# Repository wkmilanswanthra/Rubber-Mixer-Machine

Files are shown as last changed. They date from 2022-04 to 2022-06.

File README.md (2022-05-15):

# Rubber Mixer v1.0


## :eyes: Special considerations when uploading code
* Always create a **_new branch_** to upload new and edited code
* Fetch origin before making any changes to your code
* Add a well written description to each commit
* Mention every single change done
* Create a pull request and merge the branch in the main after resolving any conflicts
* If you face any problems when merging a branch watch [this video](https://youtu.be/9j0AOrO0dnw?t=1086) or contact me :full_moon_with_face: 
* Use the seperate folder named "Proteus files" to upload any proteus project files 
* Use the seperate folder named "test2" to upload new or changed header files 

## Components that need to be completed
* - [ ] Code for the Ultrasonic sensor (Detect the liquid levels once before the LCD Display starts)
* - [ ] Code for the calculation of pH values and required volumes

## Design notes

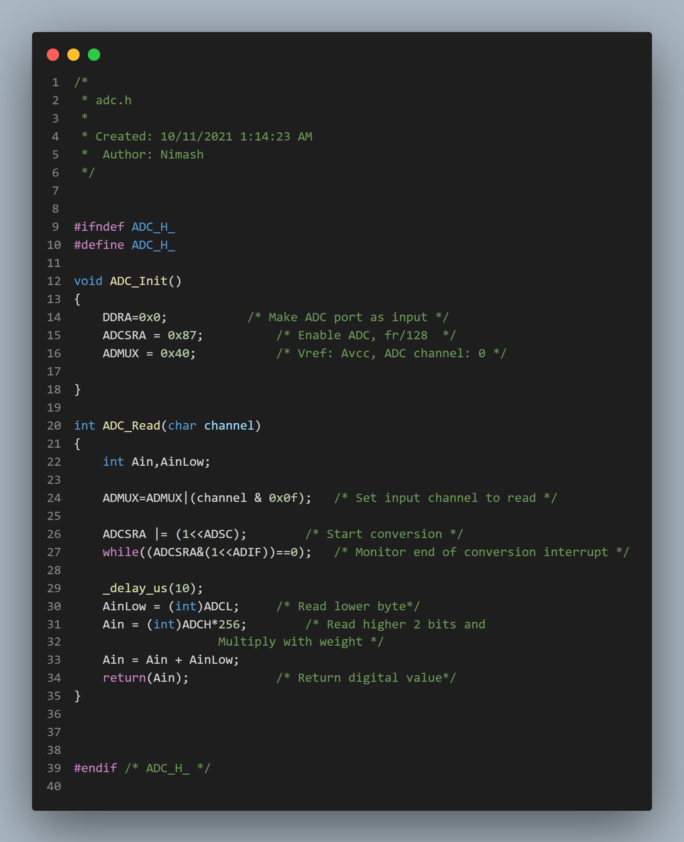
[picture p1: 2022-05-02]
NImz/code snaps/adc-h.png

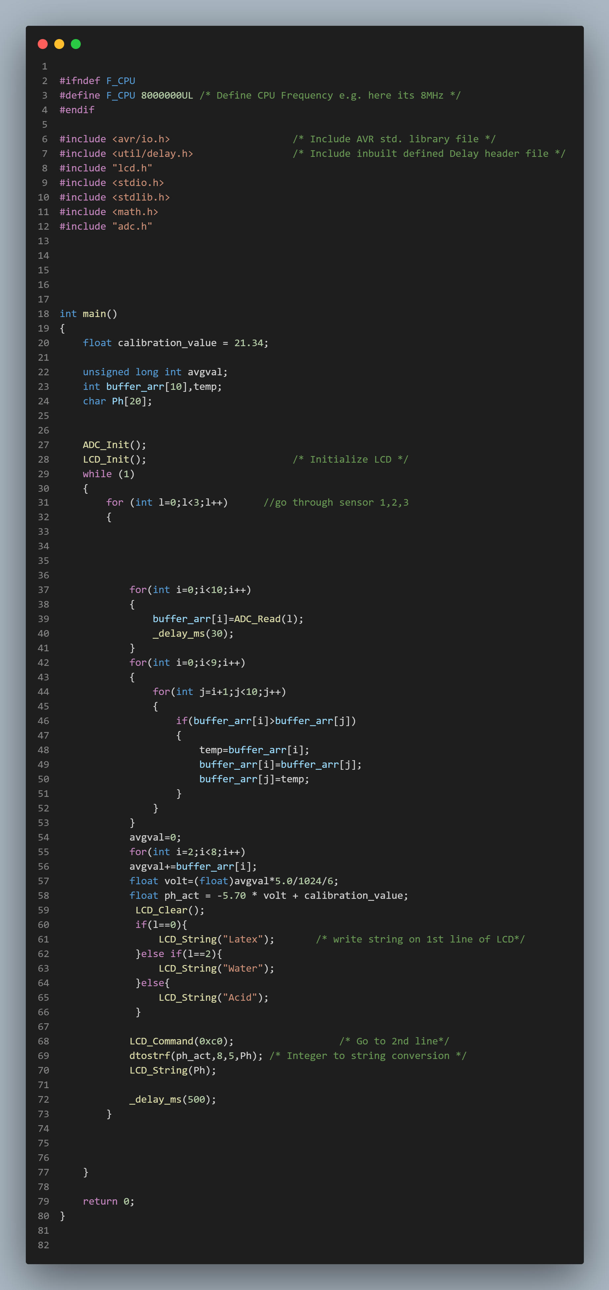
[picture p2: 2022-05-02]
NImz/code snaps/main-c.png

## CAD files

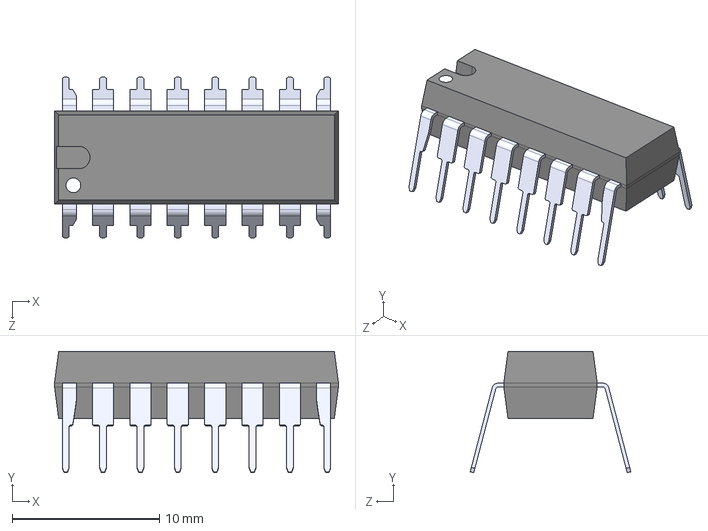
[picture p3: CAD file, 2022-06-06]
PCB and schematic/footprints/4052/CD4052BE.STEP
19.3 x 8.25 x 10.9 mm

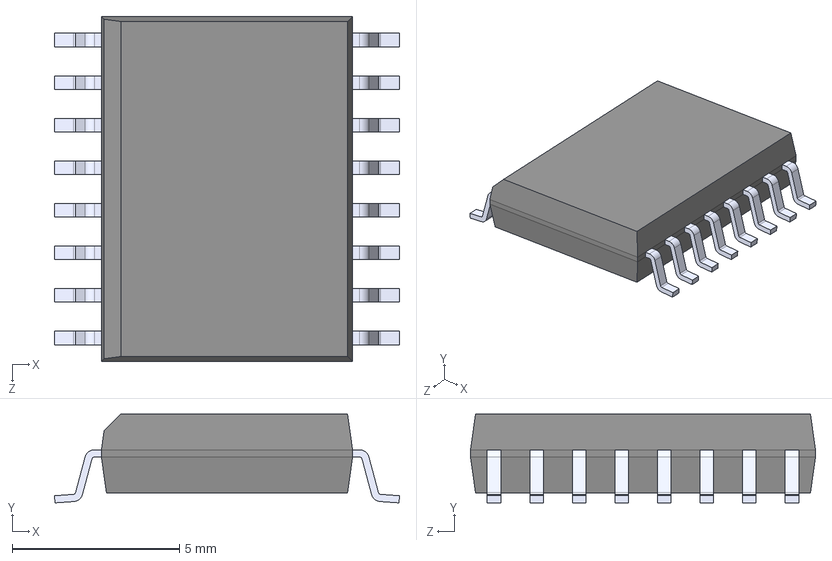
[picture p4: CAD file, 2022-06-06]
PCB and schematic/footprints/pcf8574a/i2c part 3/PCF8574ADW.step
10.3 x 2.65 x 10.3 mm

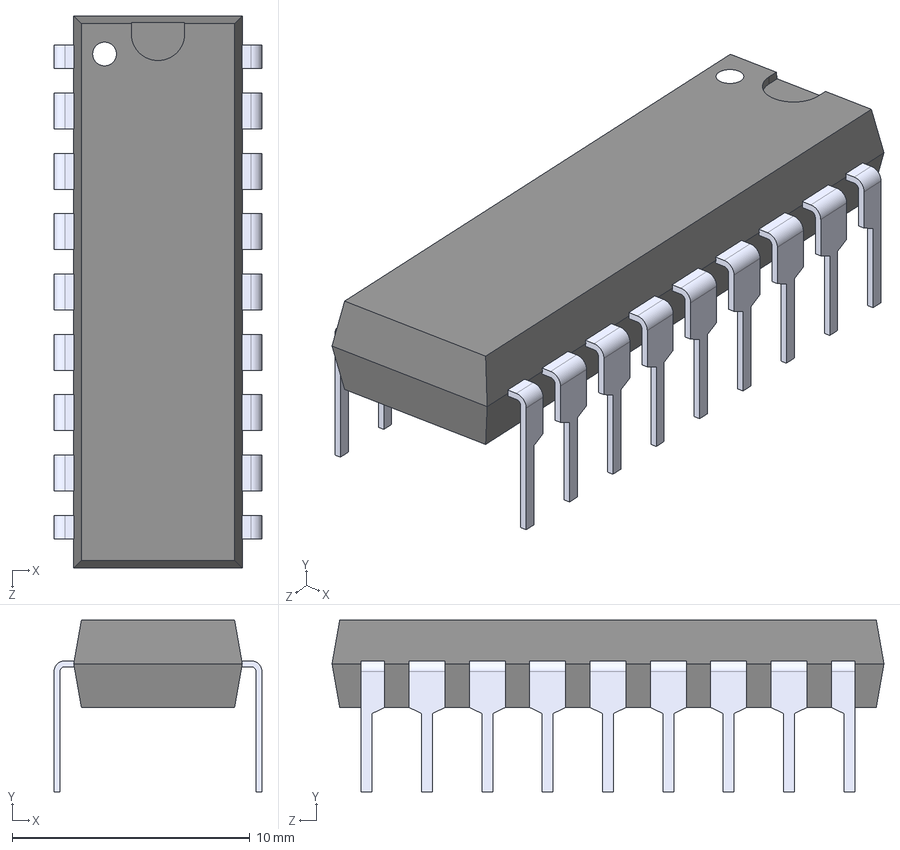
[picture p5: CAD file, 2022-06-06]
PCB and schematic/footprints/uln2803a/ULN2803A.step
8.75 x 7.23 x 23.2 mm

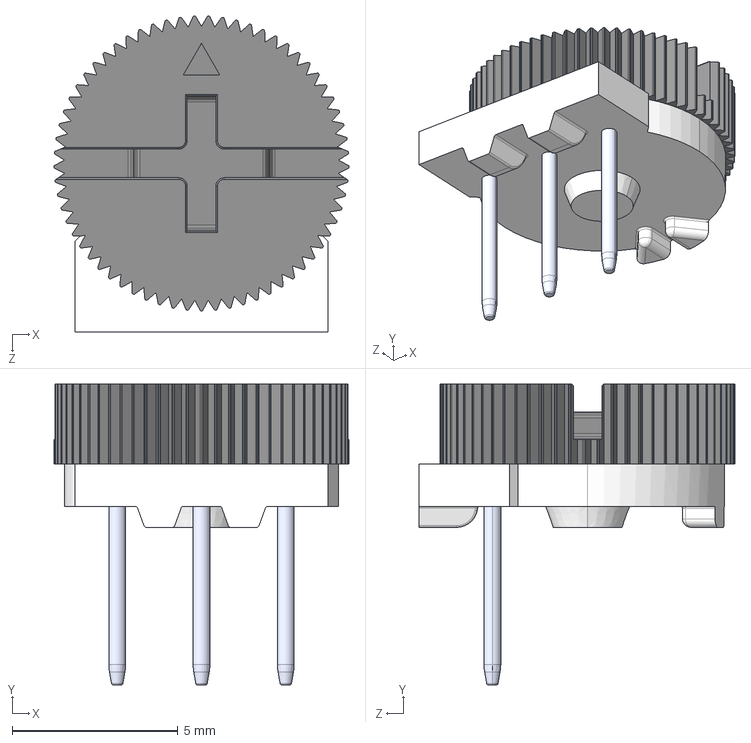
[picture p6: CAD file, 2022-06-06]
PCB and schematic/footprints/variable resistor/3352T-1-254LF.step
8.89 x 9.07 x 9.52 mm

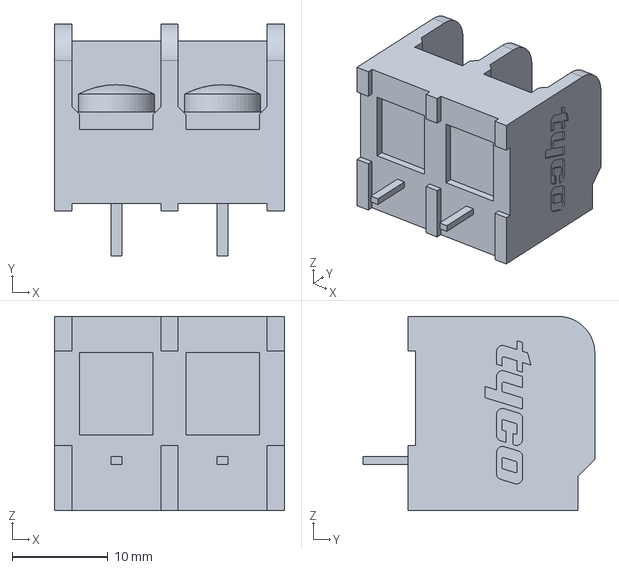
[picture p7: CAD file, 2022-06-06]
PCB and schematic/Milan - pcb/milan new/Symbols/5-1437657-7.step
24.1 x 24.3 x 20.3 mm

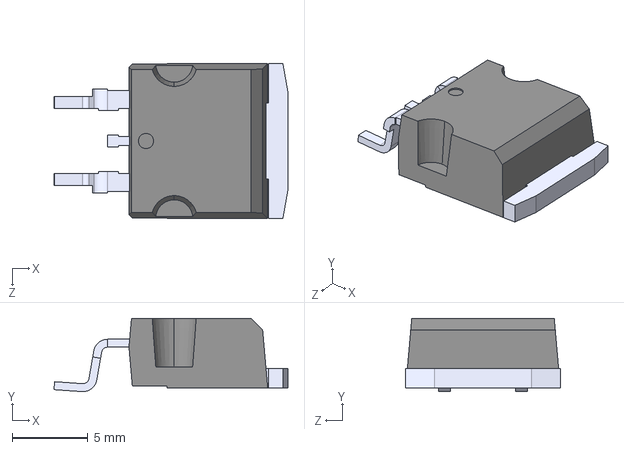
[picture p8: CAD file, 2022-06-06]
PCB and schematic/power supply/footprints/L7812.step
15.4 x 4.83 x 10.2 mm

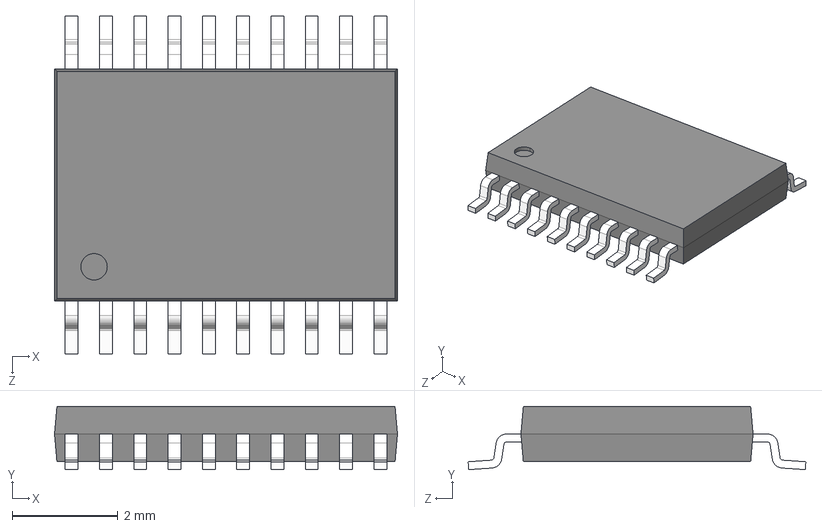
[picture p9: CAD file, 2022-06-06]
PCB and schematic/footprints/pcf8574a/PCF8574A.step
6.50 x 1.20 x 6.40 mm

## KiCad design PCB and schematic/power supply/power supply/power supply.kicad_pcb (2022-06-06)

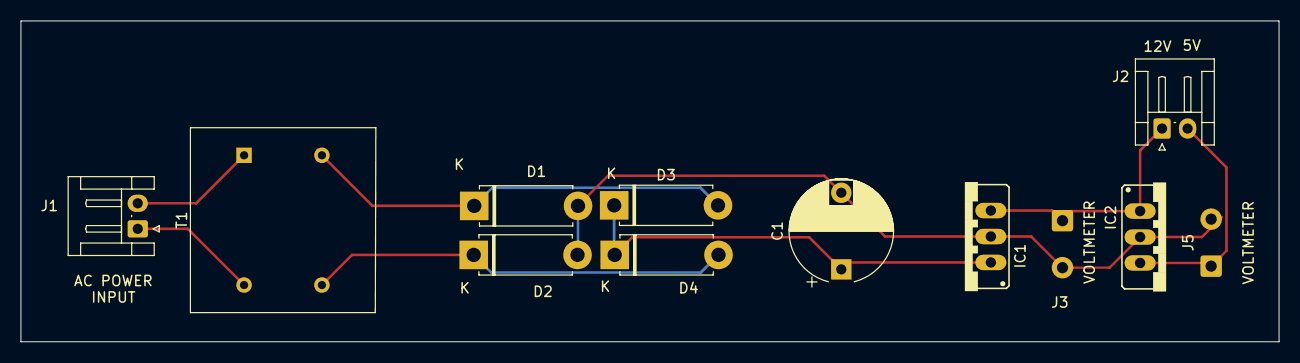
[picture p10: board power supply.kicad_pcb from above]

Board: 2 copper layers, 123.1 x 31.4 mm, 12 parts (0 on the bottom side), 7 nets.

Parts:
C1: C_Polarized; CP_Radial_D10.0mm_P7.50mm
D1, D2, D3, D4: D; D_5W_P10.16mm_Horizontal
IC1, IC2: L7812; 78XXS
J1, J2: Conn_01x02_Female; JST_EH_S2B-EH_1x02_P2.50mm_Horizontal
J3, J5: Conn_01x02_Female; SolderWire-0.5sqmm_1x02_P4.6mm_D0.9mm_OD2.1mm
T1: Transformer_1P_1S; Transformer_NF_ETAL_P3324

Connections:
-VDC: C1.2, D1.2 (A), D2.2 (A), IC1.GND, IC2.GND, J3.2, J5.2
unnamed: D1.1 (K), D3.2 (A), T1.3 (SB)
unnamed: D2.1 (K), D4.2 (A), T1.4 (SA)
unnamed: IC1.OUT, IC2.IN, J2.1, J3.1
unnamed: IC2.OUT, J2.2, J5.1
VAC: J1.1, J1.2, T1.1 (AA), T1.6 (AB)
VS: C1.1, D3.1 (K), D4.1 (K), IC1.IN

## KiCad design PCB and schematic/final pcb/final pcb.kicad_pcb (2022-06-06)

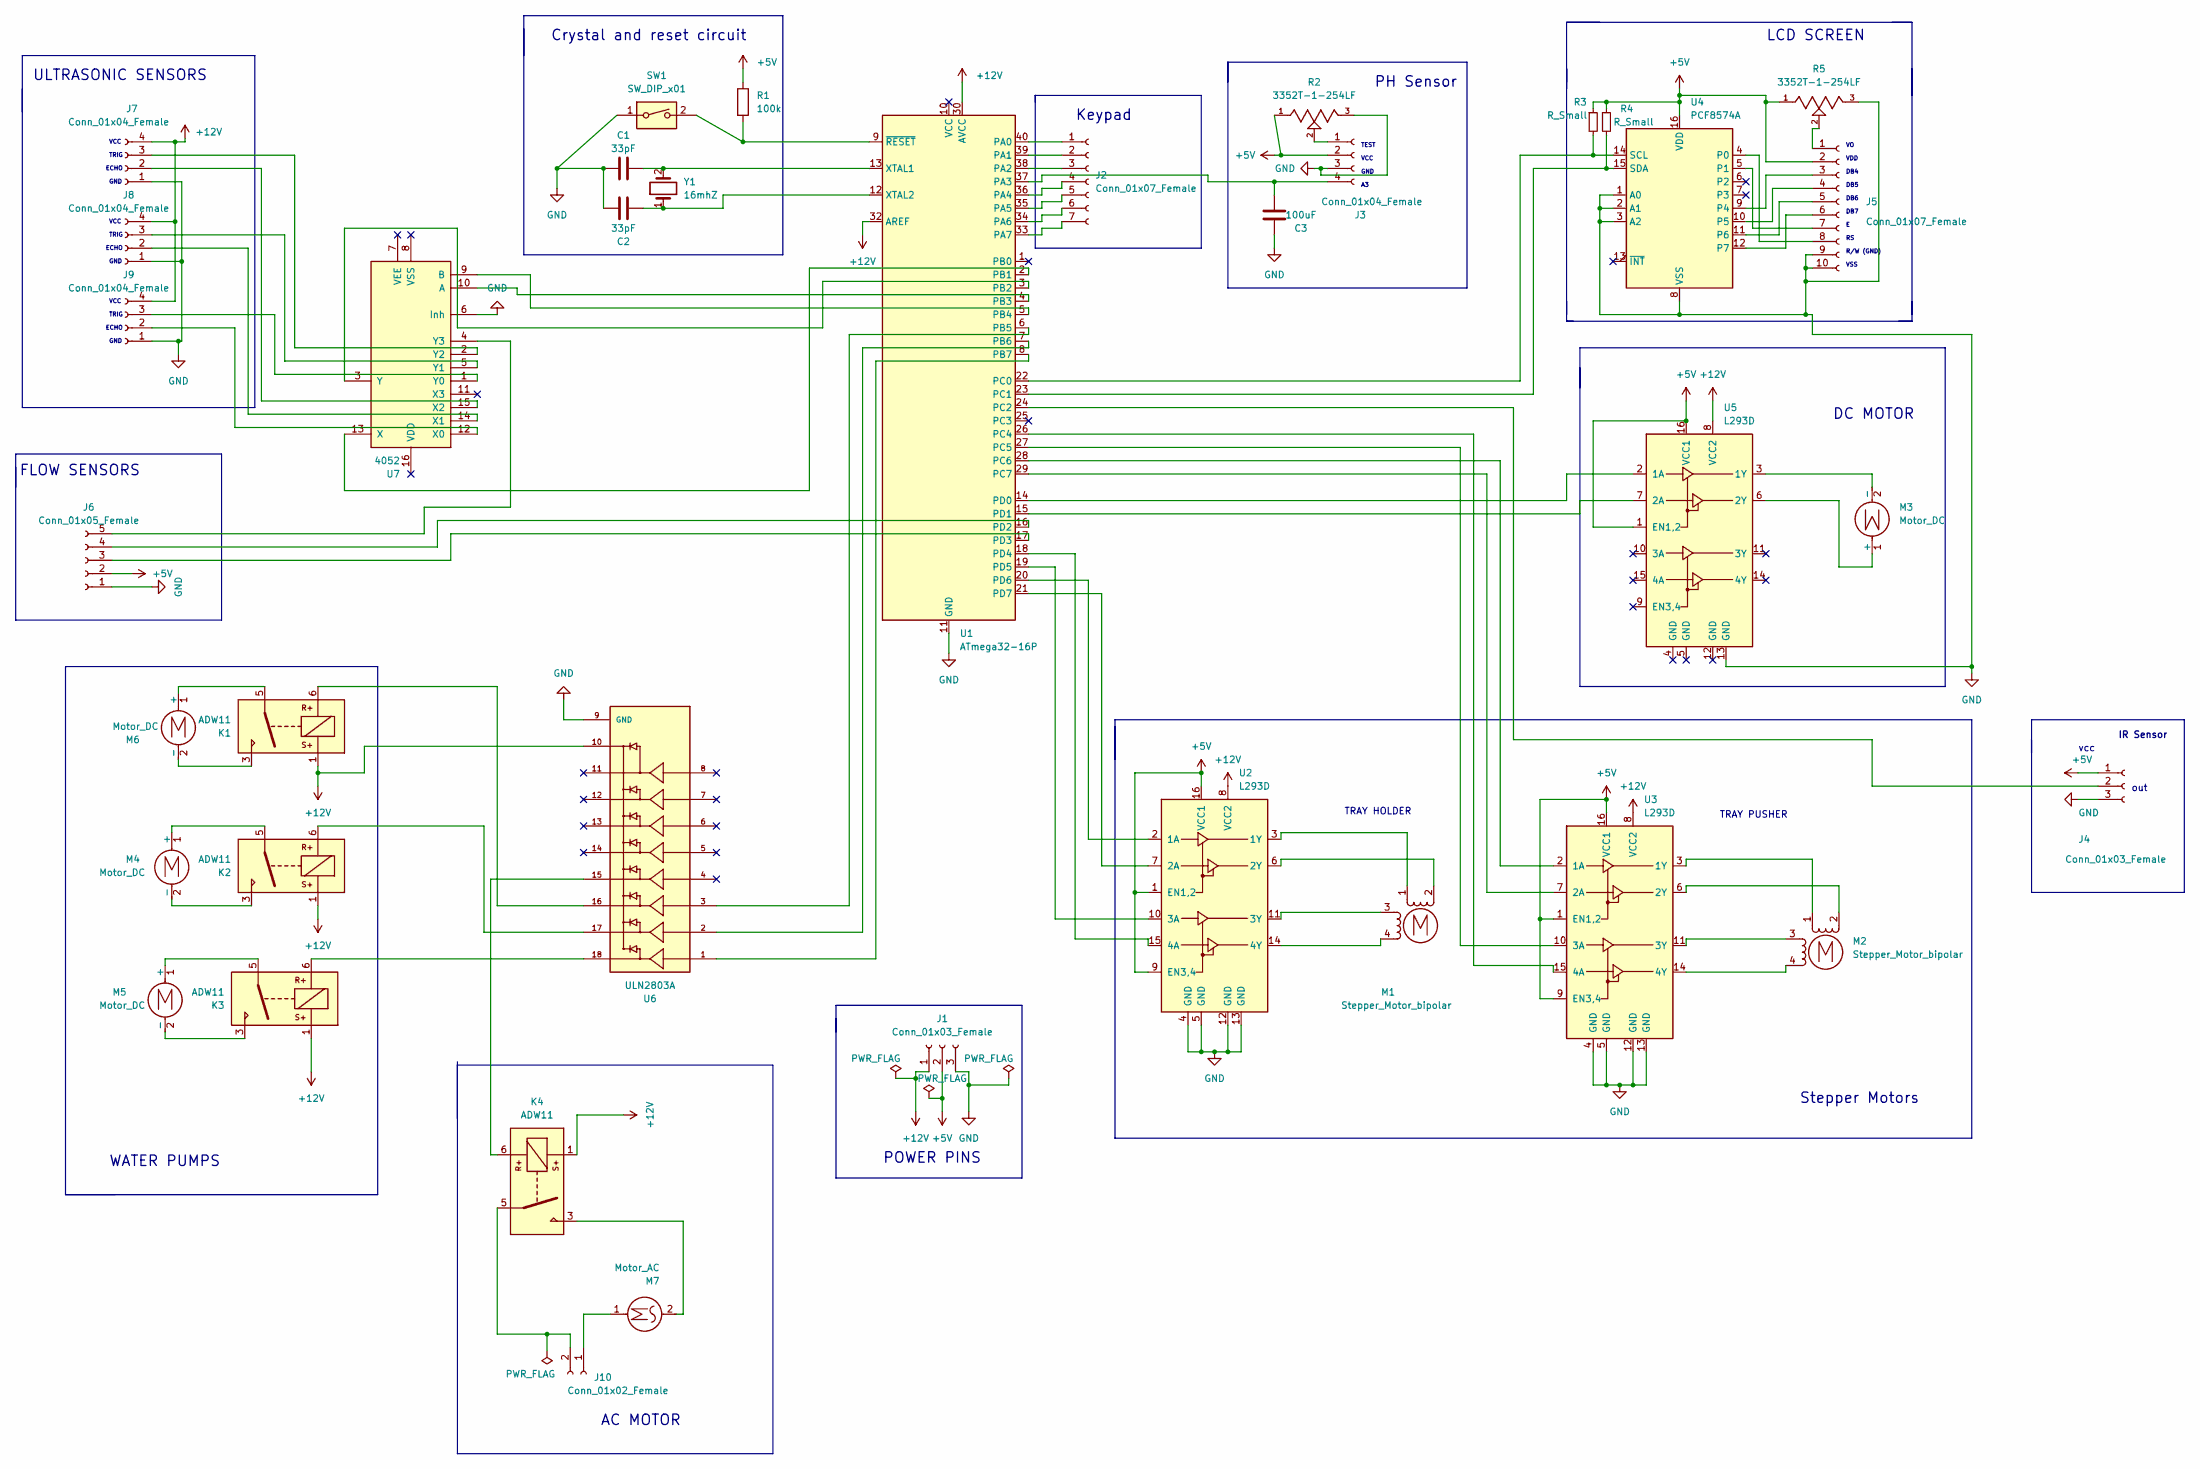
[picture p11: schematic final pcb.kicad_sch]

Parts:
C1: 33pF; C_Disc_D7.0mm_W2.5mm_P5.00mm
C2: 33pF; C_Disc_D7.5mm_W2.5mm_P5.00mm
C3: 100uF; C_Disc_D7.5mm_W2.5mm_P5.00mm
J1: Conn_01x03_Female; JST_EH_S3B-EH_1x03_P2.50mm_Horizontal
J2: Conn_01x07_Female; JST_EH_S7B-EH_1x07_P2.50mm_Horizontal
J3: Conn_01x04_Female; SolderWire-0.1sqmm_1x04_P3.6mm_D0.4mm_OD1mm
J4: Conn_01x03_Female; PinHeader_1x03_P2.54mm_Horizontal
J5: Conn_01x07_Female; JST_EH_S10B-EH_1x10_P2.50mm_Horizontal
J6: Conn_01x05_Female; JST_EH_S5B-EH_1x05_P2.50mm_Horizontal
J7, J8, J9: Conn_01x04_Female; JST_EH_S4B-EH_1x04_P2.50mm_Horizontal
J10: Conn_01x02_Female; JST_EH_B2B-EH-A_1x02_P2.50mm_Vertical
K1, K2, K3, K4: ADW11; Relay_1P1T_NO_10x24x18.8mm_Panasonic_ADW11xxxxW_THT
M1, M2: Stepper_Motor_bipolar; PinHeader_1x04_P2.54mm_Horizontal
M3, M4, M5, M6: Motor_DC; PinHeader_1x02_P2.54mm_Horizontal
M7: Motor_AC; PinHeader_1x02_P2.54mm_Horizontal
R1: 100k; R_Axial_DIN0204_L3.6mm_D1.6mm_P7.62mm_Horizontal
R2, R5: 3352T-1-254LF; TRIM_3352T-1-254LF; PARTREV 08/19
R3, R4: R_Small; R_0402_1005Metric
SW1: SW_DIP_x01; SW_DIP_SPSTx01_Slide_6.7x4.1mm_W7.62mm_P2.54mm_LowProfile
U1: ATmega32-16P; DIP-40_W15.24mm
U2, U3, U5: L293D; DIP-16_W7.62mm
U4: PCF8574A; SOIC127P1030X265-16N
U6: ULN2803A; DIP850W46P254L2324H393Q18; PARTREV 4
U7: 4052; DIP794W45P254L1969H508Q16
Y1: 16mhZ; Crystal_C38-LF_D3.0mm_L8.0mm_Vertical

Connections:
+5V: J1.2, J3.2, J4.1, J5.2, J6.2, R1.1, R2.1, R3.1, R4.1, R5.1, U2.1 (EN1,2), U2.9 (EN3,4), U2.16 (VCC1), U3.1 (EN1,2), U3.9 (EN3,4), U3.16 (VCC1), U4.16 (VDD), U5.1 (EN1,2), U5.16 (VCC1)
+12V: J1.1, J7.4, J8.4, J9.4, K1.1, K2.1, K3.1, K4.1, U1.30 (AVCC), U1.32 (AREF), U2.8 (VCC2), U3.8 (VCC2), U5.8 (VCC2), U6.10
GND: C1.2, C2.2, C3.2, J1.3, J3.3, J4.3, J5.9, J5.10, J6.1, J7.1, J8.1, J9.1, R2.3, R5.3, SW1.1, U1.11 (GND), U1.31 (GND), U2.4 (GND), U2.5 (GND), U2.12 (GND), U2.13 (GND), U3.4 (GND), U3.5 (GND), U3.12 (GND), U3.13 (GND), U4.1 (A0), U4.2 (A1), U4.3 (A2), U4.8 (VSS), U5.13 (GND), U6.9 (GND), U7.6 (Inh)
unnamed: C1.1, U1.13 (XTAL1), Y1.2
unnamed: C2.1, U1.12 (XTAL2), Y1.1
unnamed: C3.1, J3.4, U1.37 (PA3)
unnamed: J2.1, U1.40 (PA0)
unnamed: J2.2, U1.39 (PA1)
unnamed: J2.3, U1.38 (PA2)
unnamed: J2.4, U1.36 (PA4)
unnamed: J2.5, U1.35 (PA5)
unnamed: J2.6, U1.34 (PA6)
unnamed: J2.7, U1.33 (PA7)
unnamed: J3.1, R2.2
unnamed: J4.2, U1.24 (PC2)
unnamed: J5.1, R5.2
unnamed: J5.3, U4.9 (P4)
unnamed: J5.4, U4.10 (P5)
unnamed: J5.5, U4.11 (P6)
unnamed: J5.6, U4.12 (P7)
unnamed: J5.7, U4.5 (P1)
unnamed: J5.8, U4.4 (P0)
unnamed: J6.3, U1.17 (PD3)
unnamed: J6.4, U1.16 (PD2)
unnamed: J6.5, U7.4 (Y3)
unnamed: J7.2, U7.15 (X2)
unnamed: J7.3, U7.2 (Y2)
unnamed: J8.2, U7.14 (X1)
unnamed: J8.3, U7.5 (Y1)
unnamed: J9.2, U7.12 (X0)
unnamed: J9.3, U7.1 (Y0)
unnamed: J10.1, M7.1
unnamed: J10.2, K4.5
unnamed: K1.3, M6.2 (-)
unnamed: K1.5, M6.1 (+)
unnamed: K1.6, U6.16
unnamed: K2.3, M4.2 (-)
unnamed: K2.5, M4.1 (+)
unnamed: K2.6, U6.17
unnamed: K3.3, M5.2 (-)
unnamed: K3.5, M5.1 (+)
unnamed: K3.6, U6.18
unnamed: K4.3, M7.2
unnamed: K4.6, U6.15
unnamed: M1.1, U2.3 (1Y)
unnamed: M1.2 (-), U2.6 (2Y)
unnamed: M1.3, U2.11 (3Y)
unnamed: M1.4, U2.14 (4Y)
unnamed: M2.1, U3.3 (1Y)
unnamed: M2.2 (-), U3.6 (2Y)
unnamed: M2.3, U3.11 (3Y)
unnamed: M2.4, U3.14 (4Y)
unnamed: M3.1 (+), U5.6 (2Y)
unnamed: M3.2 (-), U5.3 (1Y)
unnamed: R1.2, SW1.2, U1.9 (~RESET)
unnamed: R3.2, U1.22 (PC0), U4.14 (SCL)
unnamed: R4.2, U1.23 (PC1), U4.15 (SDA)
unnamed: U1.2 (PB1), U7.13 (X)
unnamed: U1.3 (PB2), U7.3 (Y)
unnamed: U1.4 (PB3), U7.10 (A)
unnamed: U1.5 (PB4), U7.9 (B)
unnamed: U1.6 (PB5), U6.3
unnamed: U1.7 (PB6), U6.2
unnamed: U1.8 (PB7), U6.1
unnamed: U1.14 (PD0), U5.2 (1A)
unnamed: U1.15 (PD1), U5.7 (2A)
unnamed: U1.18 (PD4), U2.15 (4A)
unnamed: U1.19 (PD5), U2.10 (3A)
unnamed: U1.20 (PD6), U2.2 (1A)
unnamed: U1.21 (PD7), U2.7 (2A)
unnamed: U1.26 (PC4), U3.15 (4A)
unnamed: U1.27 (PC5), U3.10 (3A)
unnamed: U1.28 (PC6), U3.2 (1A)
unnamed: U1.29 (PC7), U3.7 (2A)

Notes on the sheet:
TRIG
GND
TRAY PUSHER
DC MOTOR
VCC
R/W (GND)
VSS
out
VDD
AC MOTOR
FLOW SENSORS
ECHO
DB5
DB7
PH Sensor
LCD SCREEN
DB4
Crystal and reset circuit
IR Sensor
vcc
ULTRASONIC SENSORS
TRAY HOLDER
WATER PUMPS
TEST
Keypad
POWER PINS
Stepper Motors
DB6

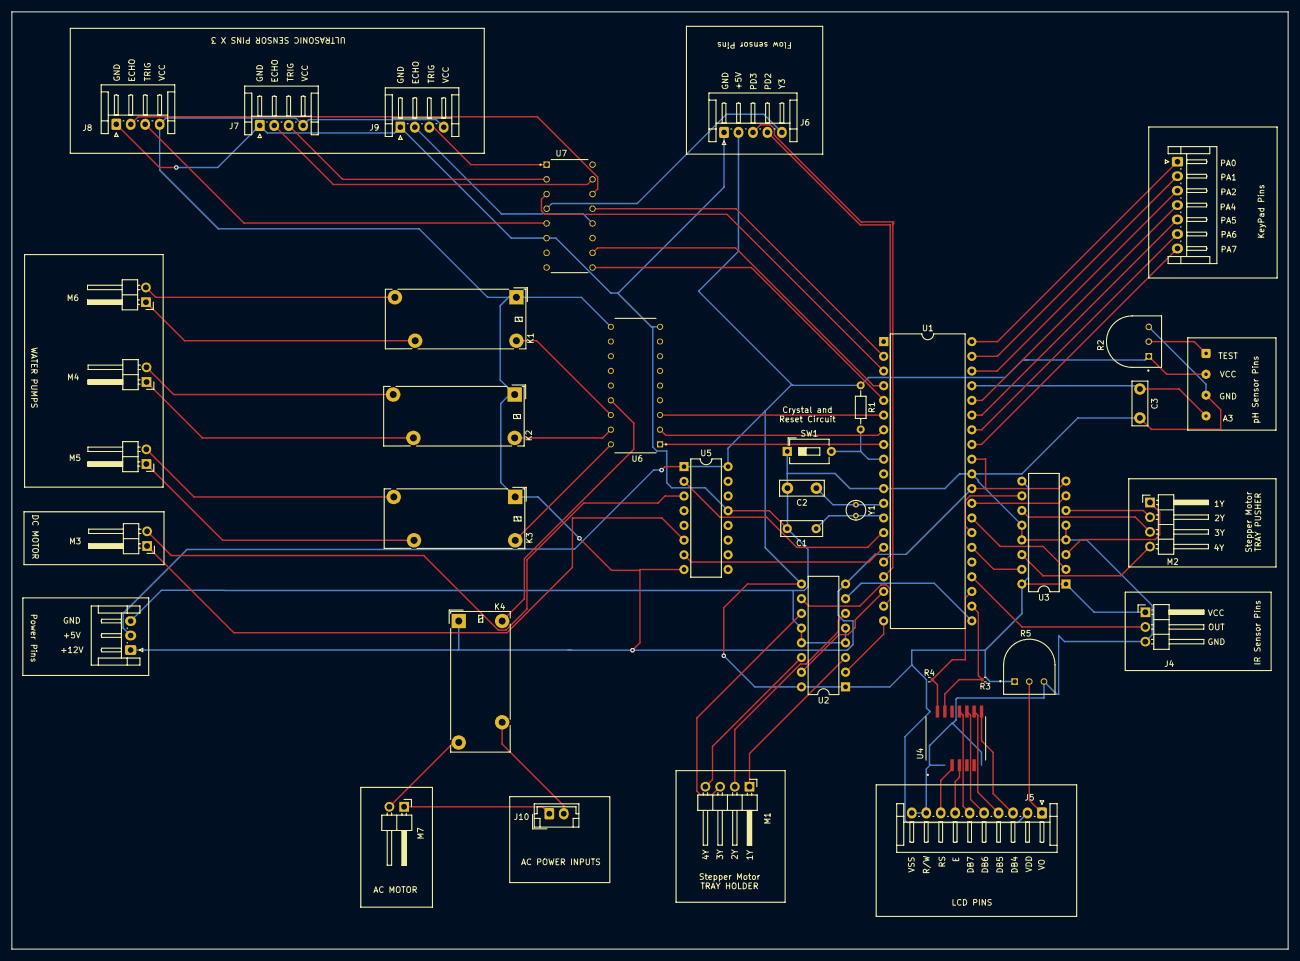
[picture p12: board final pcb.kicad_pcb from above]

Board: 2 copper layers, 220.6 x 162.0 mm, 38 parts (0 on the bottom side), 74 nets.

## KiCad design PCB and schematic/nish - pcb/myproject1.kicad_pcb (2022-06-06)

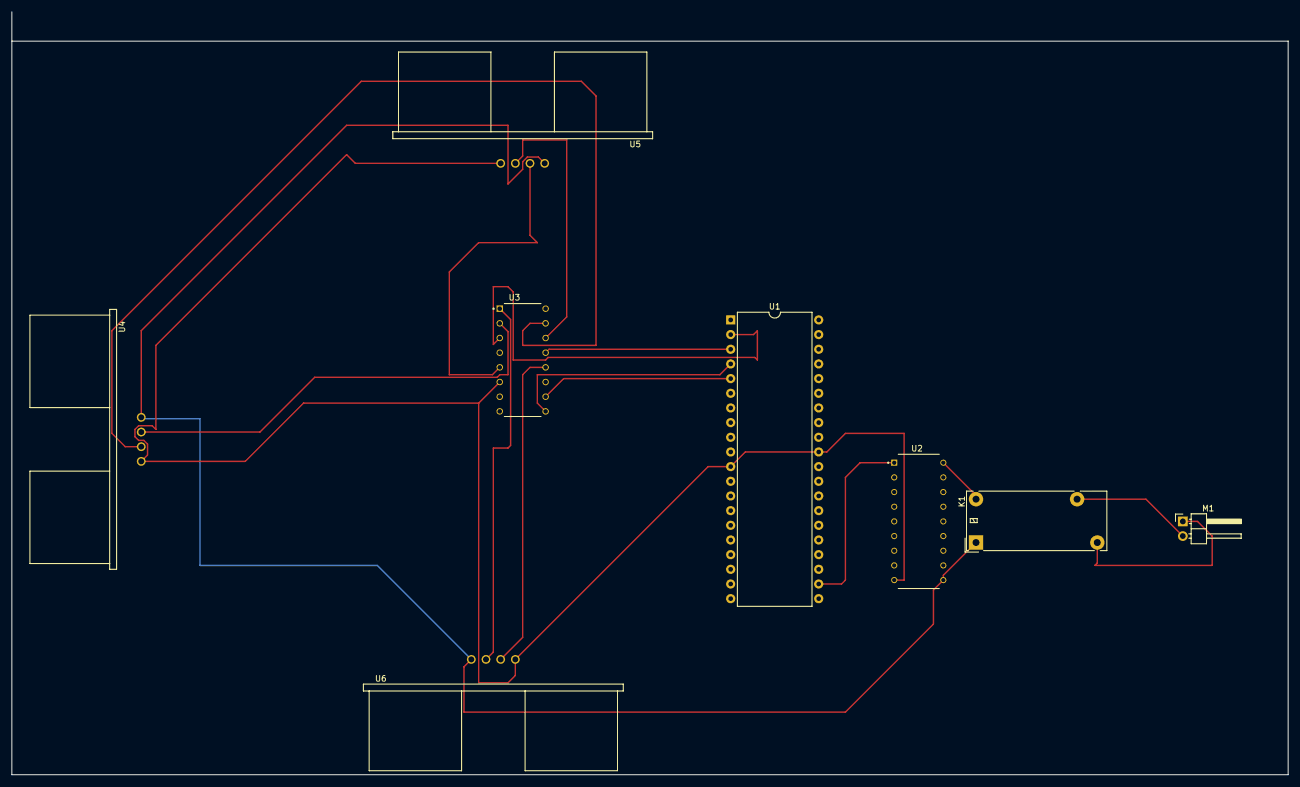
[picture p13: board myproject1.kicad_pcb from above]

Board: 2 copper layers, 221.0 x 132.1 mm, 8 parts (0 on the bottom side), 16 nets.

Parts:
K1: ADW11; Relay_1P1T_NO_10x24x18.8mm_Panasonic_ADW11xxxxW_THT
M1: Motor_AC; PinHeader_1x02_P2.54mm_Horizontal
U1: ATmega32L-8P; DIP-40_W15.24mm
U2: ULN2803A; DIP850W46P254L2324H393Q18
U3: CD4052B; DIP794W45P254L1969H508Q16
U4, U5, U6: HC-SR04; XCVR_HC-SR04

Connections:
+12V: K1.1, U2.10 (COM), U4.1 (VCC), U5.1 (VCC), U6.1 (VCC)
AC: K1.5, M1.2
Earth: U1.11 (GND), U1.31 (GND), U2.9 (GND), U3.6 (INH), U4.4 (GND), U5.4 (GND), U6.4 (GND)
unnamed: K1.3, M1.1
unnamed: K1.6, U2.18 (O1)
unnamed: U1.2 (PB1), U3.3 (Y)
unnamed: U1.3 (PB2), U3.13 (X)
unnamed: U1.4 (PB3), U3.9 (B)
unnamed: U1.5 (PB4), U3.10 (A)
unnamed: U1.22 (PC0), U2.1 (I1)
unnamed: U3.1 (Y0), U6.2 (TRIG)
unnamed: U3.2 (Y2), U4.2 (TRIG)
unnamed: U3.5 (Y1), U5.2 (TRIG)
unnamed: U3.12 (X0), U6.3 (ECHO)
unnamed: U3.14 (X1), U5.3 (ECHO)
unnamed: U3.15 (X2), U4.3 (ECHO)

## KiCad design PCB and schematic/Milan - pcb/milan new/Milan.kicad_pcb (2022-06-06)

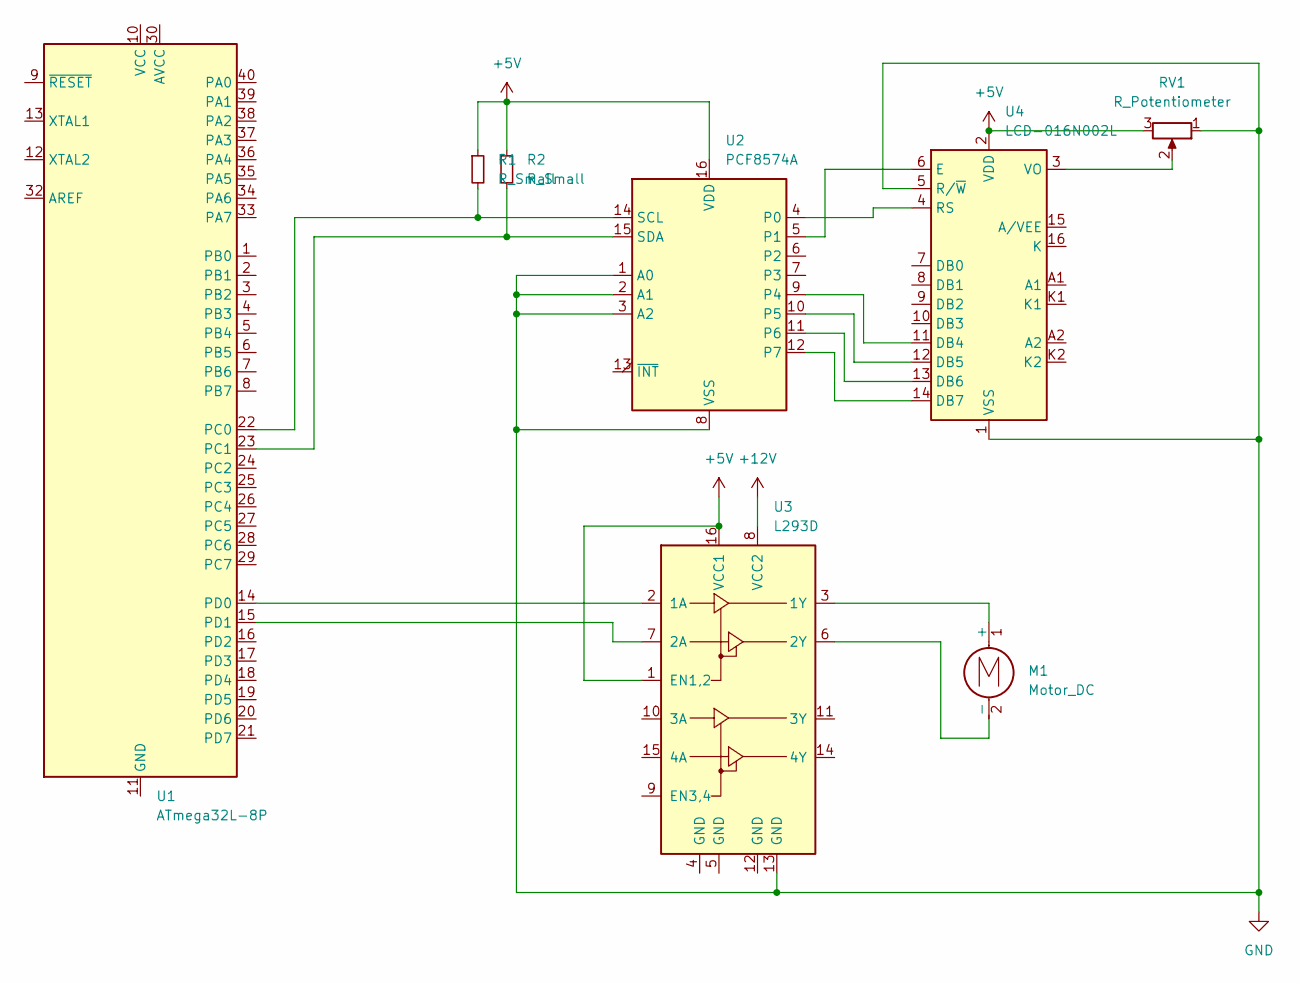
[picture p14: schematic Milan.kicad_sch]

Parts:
M1: Motor_DC; PinHeader_1x02_P2.54mm_Horizontal
R1, R2: R_Small; R_0402_1005Metric
RV1: R_Potentiometer; Potentiometer_ACP_CA6-VSMD_Vertical
U1: ATmega32L-8P; DIP-40_W15.24mm
U2: PCF8574A; DIL16
U3: L293D; DIP-16_W7.62mm
U4: LCD-016N002L

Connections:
+5V: R1.1, R2.1, RV1.3, U2.16 (VDD), U3.1 (EN1,2), U3.16 (VCC1), U4.2 (VDD)
+12V: U3.8 (VCC2)
GND: RV1.1, U2.1 (A0), U2.2 (A1), U2.3 (A2), U2.8 (VSS), U3.13 (GND), U4.1 (VSS), U4.5 (R/~W)
unnamed: M1.1 (+), U3.3 (1Y)
unnamed: M1.2 (-), U3.6 (2Y)
unnamed: U1.11 (GND), U1.31 (GND)
unnamed: U1.14 (PD0), U3.2 (1A)
unnamed: U1.15 (PD1), U3.7 (2A)
unnamed: R1.2, U1.22 (PC0), U2.14 (SCL)
unnamed: R2.2, U1.23 (PC1), U2.15 (SDA)
unnamed: U2.4 (P0), U4.4 (RS)
unnamed: U2.5 (P1), U4.6 (E)
unnamed: U2.9 (P4), U4.11 (DB4)
unnamed: U2.10 (P5), U4.12 (DB5)
unnamed: U2.11 (P6), U4.13 (DB6)
unnamed: U2.12 (P7), U4.14 (DB7)
unnamed: RV1.2, U4.3 (VO)

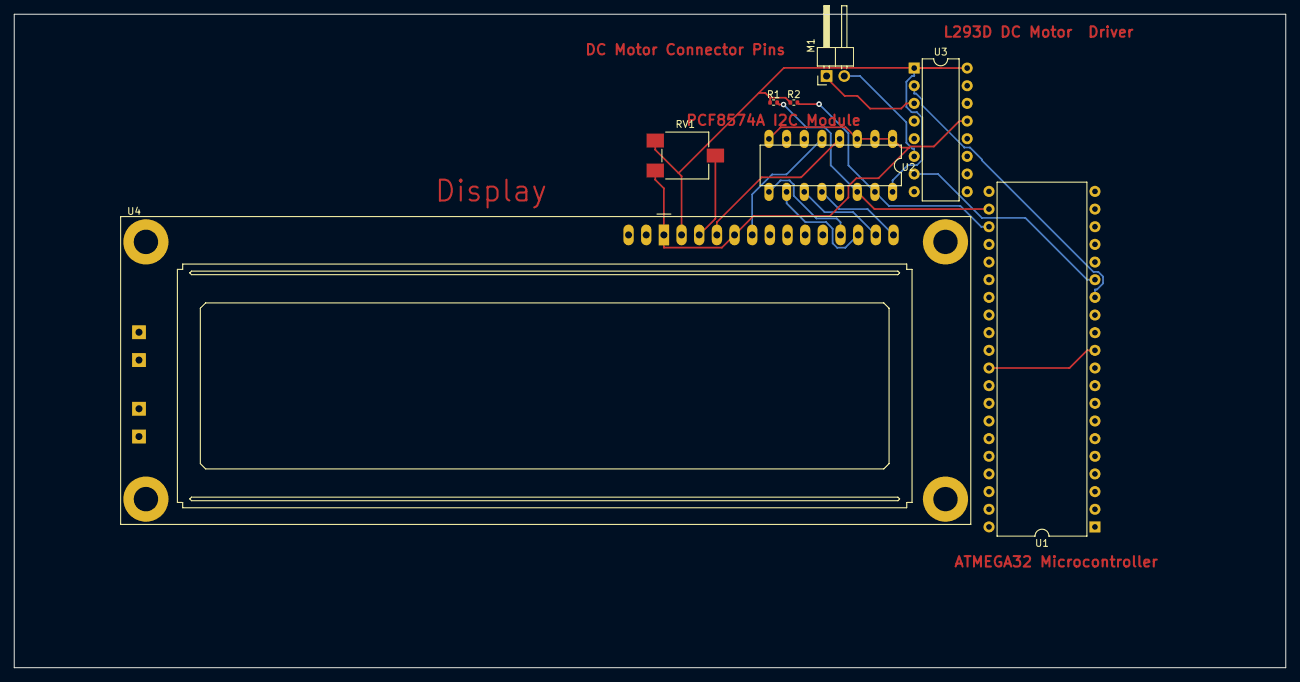
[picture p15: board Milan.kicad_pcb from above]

Board: 2 copper layers, 182.9 x 94.0 mm, 8 parts (0 on the bottom side), 16 nets.

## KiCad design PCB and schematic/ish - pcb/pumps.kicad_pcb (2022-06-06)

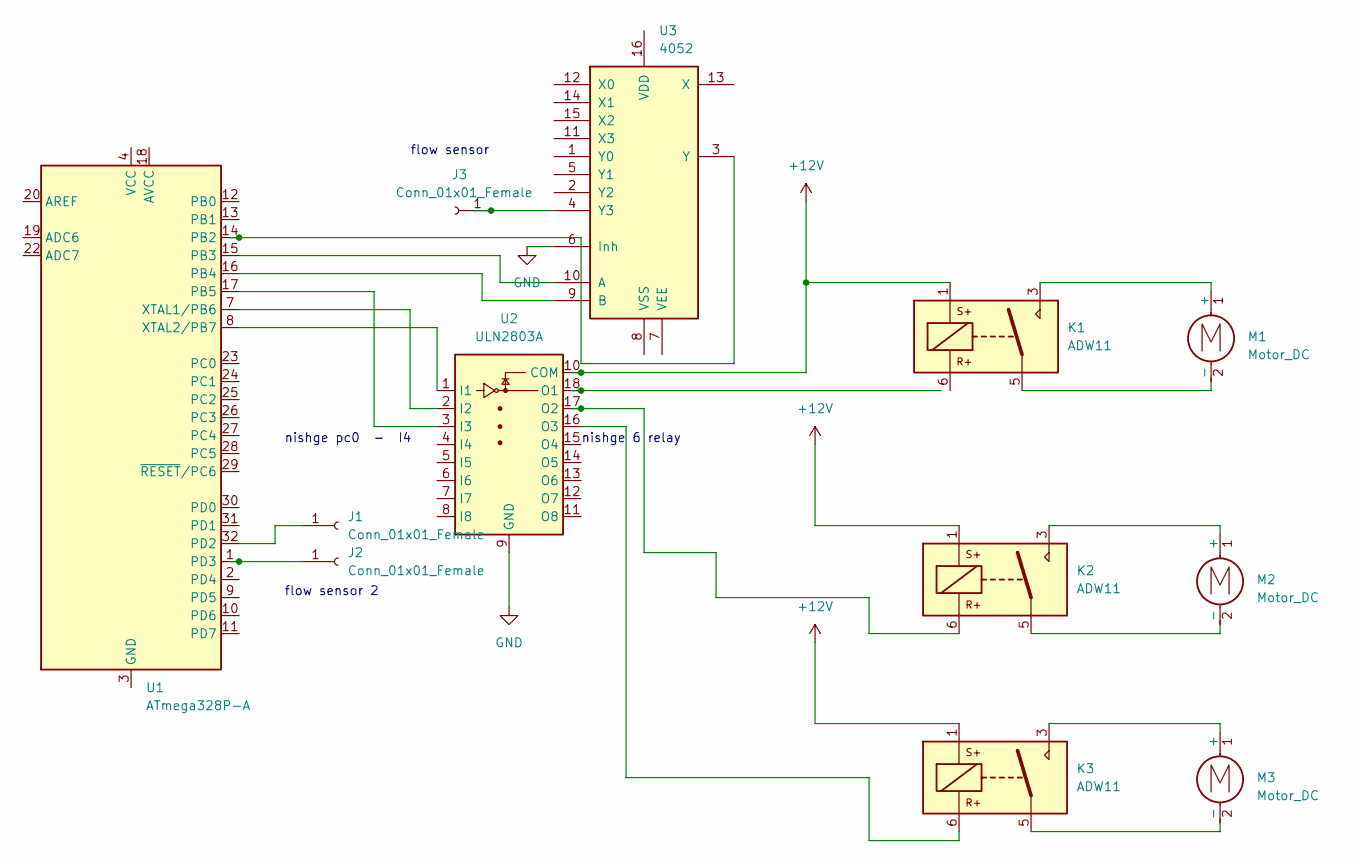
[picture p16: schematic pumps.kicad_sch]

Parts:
J1, J2, J3: Conn_01x01_Female; PinHeader_1x02_P1.00mm_Horizontal
K1, K2, K3: ADW11; Relay_1P1T_NO_10x24x18.8mm_Panasonic_ADW11xxxxW_THT
M1, M2, M3: Motor_DC; PinHeader_1x02_P2.54mm_Horizontal
U1: ATmega328P-A; TQFP-32_7x7mm_P0.8mm
U2: ULN2803A; DIP850W46P254L2324H393Q18
U3: 4052; DIP794W45P254L1969H508Q16

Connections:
+12V: K1.1, K2.1, K3.1, U2.10 (COM)
GND: U2.9 (GND), U3.6 (Inh)
unnamed: K1.3, M1.1 (+)
unnamed: K1.5, M1.2 (-)
unnamed: K2.3, M2.1 (+)
unnamed: K2.5, M2.2 (-)
unnamed: K2.6, U2.17 (O2)
unnamed: K3.3, M3.1 (+)
unnamed: K3.5, M3.2 (-)
unnamed: K3.6, U2.16 (O3)
unnamed: J2.1, U1.1 (PD3)
unnamed: U1.4 (VCC), U1.6 (VCC)
unnamed: U1.7 (XTAL1/PB6), U2.2 (I2)
unnamed: U1.8 (XTAL2/PB7), U2.1 (I1)
unnamed: U1.14 (PB2), U3.3 (Y)
unnamed: U1.15 (PB3), U3.10 (A)
unnamed: U1.16 (PB4), U3.9 (B)
unnamed: U1.17 (PB5), U2.3 (I3)
unnamed: U1.3 (GND), U1.5 (GND), U1.21 (GND)
unnamed: J1.1, U1.32 (PD2)
unnamed: J3.1, U3.4 (Y3)

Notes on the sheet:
nishge pc0 - I4
nishge 6 relay
flow sensor
flow sensor 2

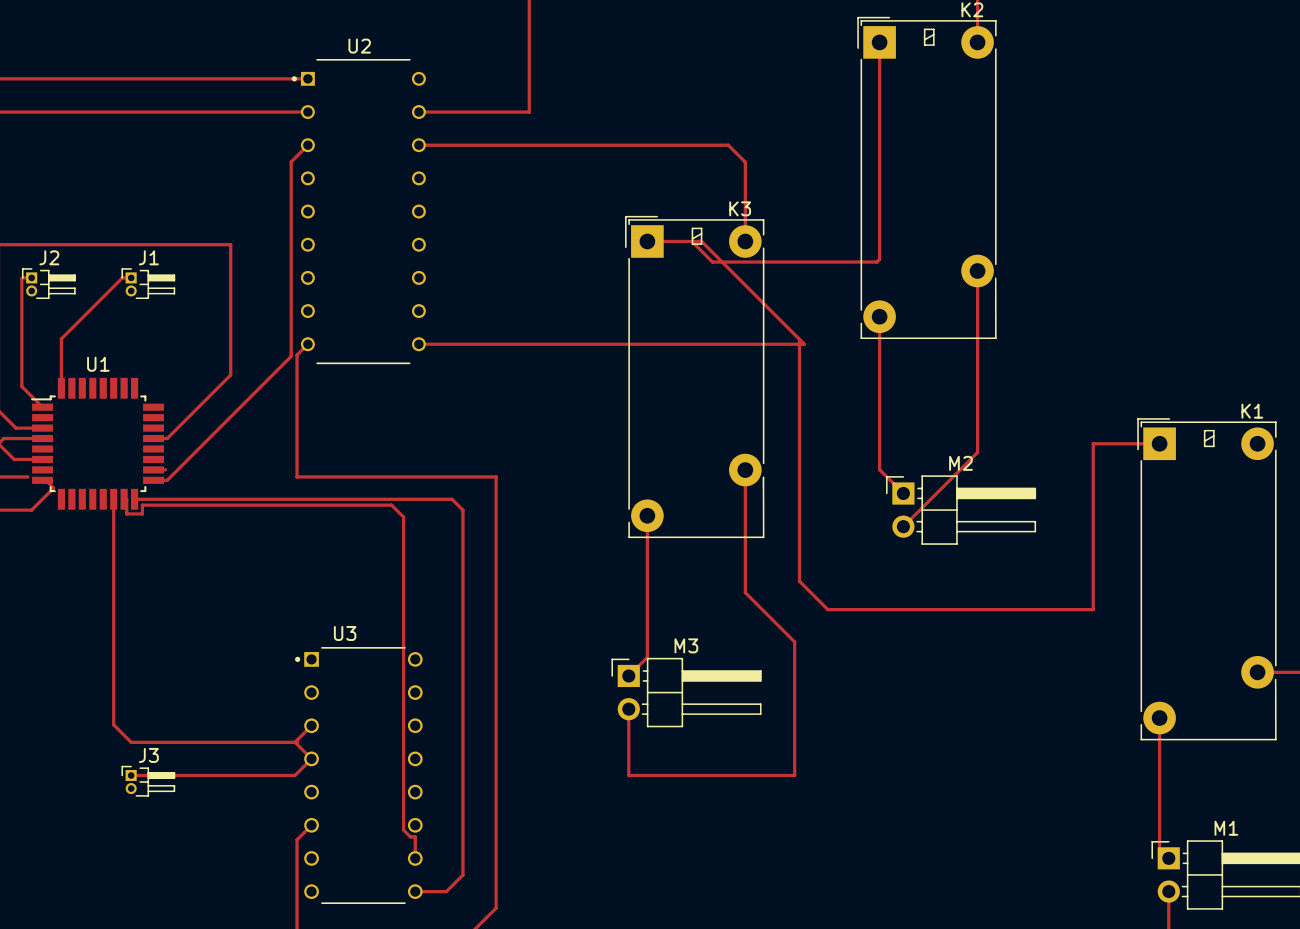
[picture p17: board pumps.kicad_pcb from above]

Board: 2 copper layers, 12 parts (0 on the bottom side), 21 nets.

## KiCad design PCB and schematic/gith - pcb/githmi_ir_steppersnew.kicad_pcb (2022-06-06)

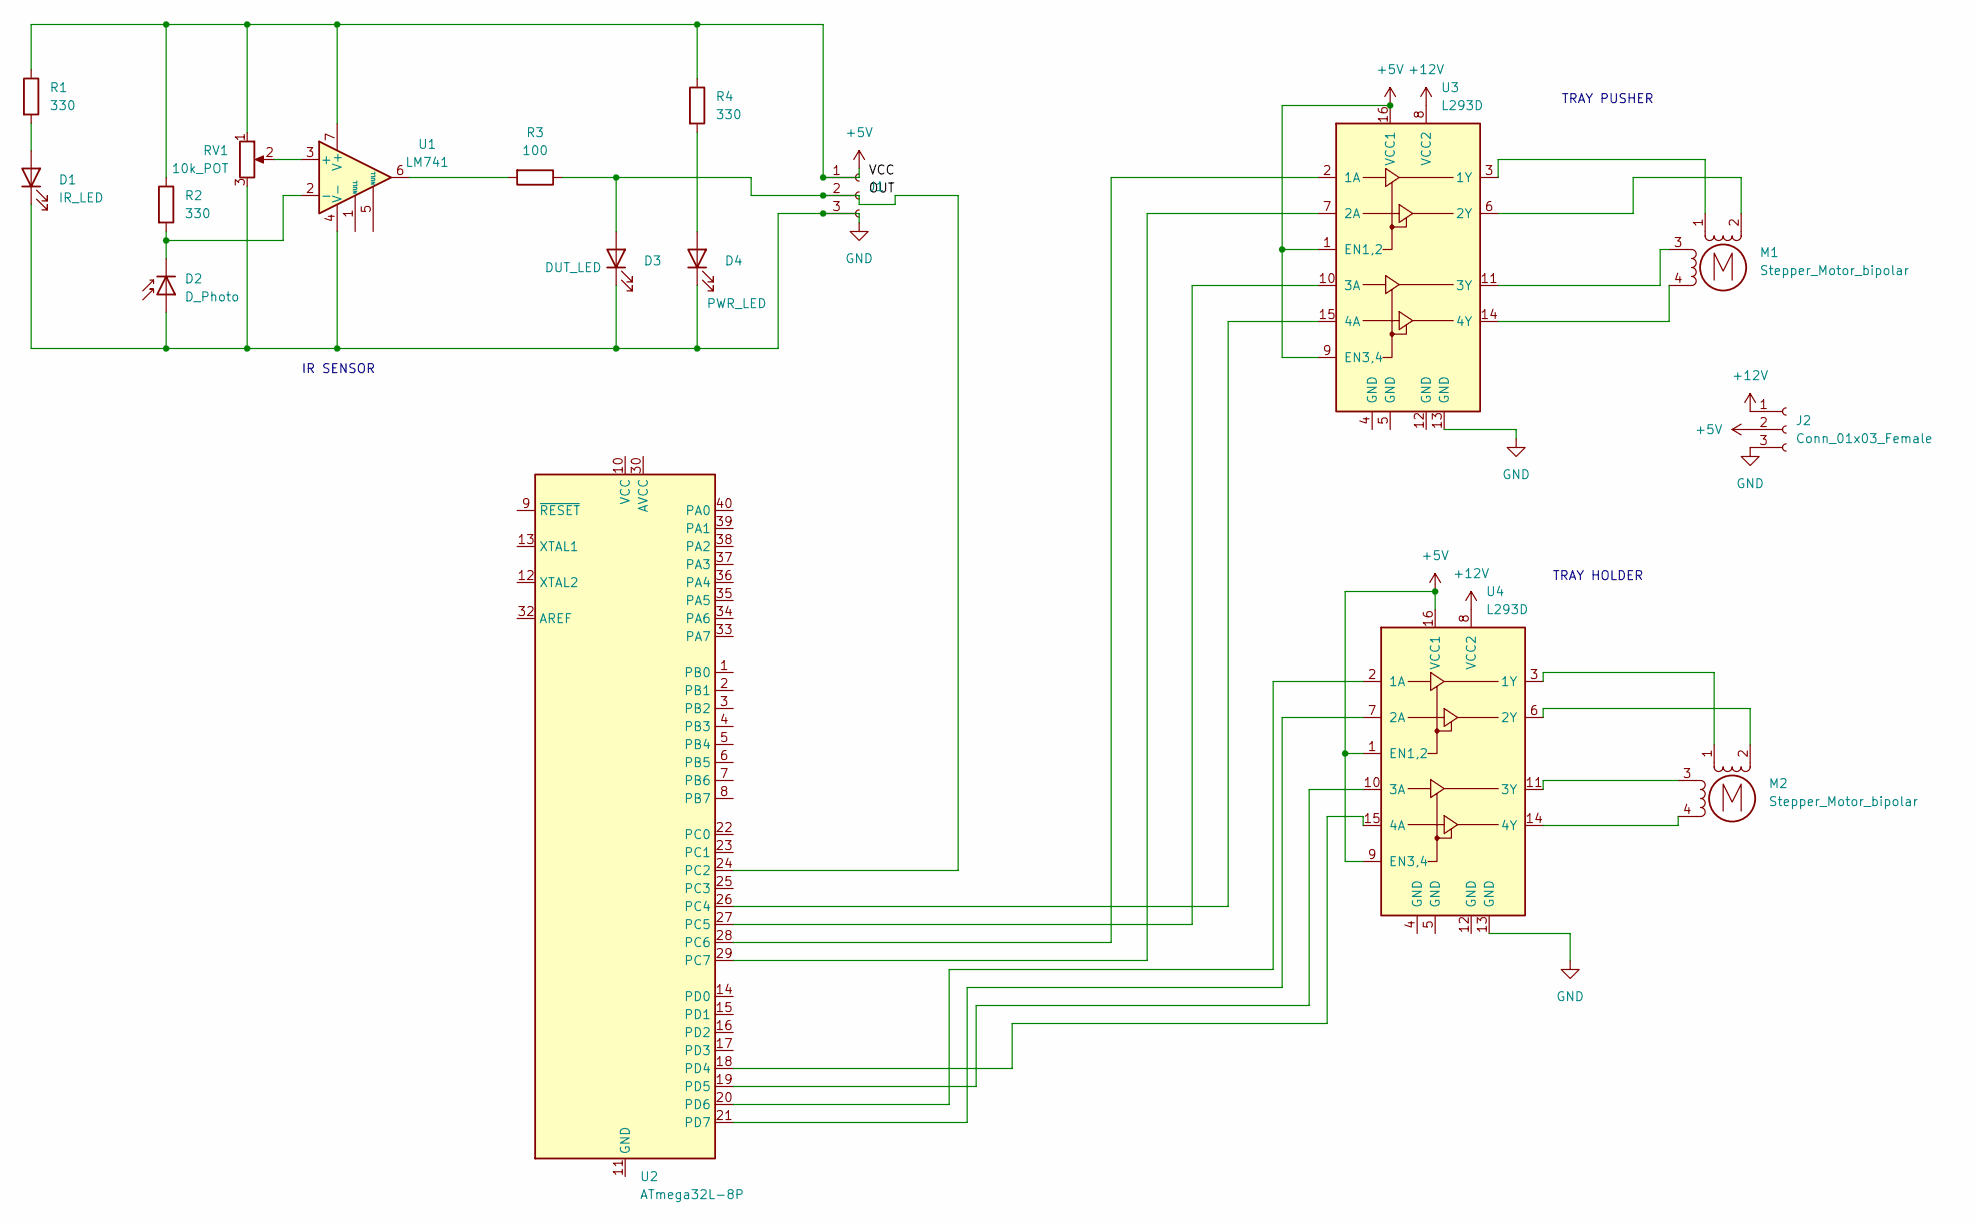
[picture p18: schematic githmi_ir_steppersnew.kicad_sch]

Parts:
D1: IR_LED; LED_D3.0mm_Horizontal_O1.27mm_Z2.0mm
D2: D_Photo; LED_D3.0mm_Horizontal_O1.27mm_Z2.0mm_IRBlack
D3: DUT_LED; LED_0805_2012Metric_Pad1.15x1.40mm_HandSolder
D4: PWR_LED; LED_0805_2012Metric_Pad1.15x1.40mm_HandSolder
J1: (no value)
J2: Conn_01x03_Female; SolderWire-0.1sqmm_1x03_P3.6mm_D0.4mm_OD1mm
M1, M2: Stepper_Motor_bipolar
R1, R2, R4: 330; R_0805_2012Metric
R3: 100; R_0805_2012Metric
RV1: 10k_POT; Potentiometer_ACP_CA9-V10_Vertical_Hole
U1: LM741; SOIC-8_3.9x4.9mm_P1.27mm
U2: ATmega32L-8P; DIP-40_W15.24mm
U3, U4: L293D; DIP-16_W7.62mm

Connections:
+5V: J1.1, J2.2, R1.1, R2.1, R4.1, RV1.1, U1.7 (V+), U3.1 (EN1,2), U3.9 (EN3,4), U3.16 (VCC1), U4.1 (EN1,2), U4.9 (EN3,4), U4.16 (VCC1)
+12V: J2.1, U3.8 (VCC2), U4.8 (VCC2)
GND: D1.1 (K), D2.2 (A), D3.1 (K), D4.1 (K), J1.3, J2.3, RV1.3, U1.4 (V-), U3.13 (GND), U4.13 (GND)
unnamed: D1.2 (A), R1.2
unnamed: D2.1 (K), R2.2, U1.2 (-)
unnamed: D3.2 (A), J1.2, R3.1, U2.24 (PC2)
unnamed: D4.2 (A), R4.2
unnamed: M1.1, U3.3 (1Y)
unnamed: M1.2 (-), U3.6 (2Y)
unnamed: M1.3, U3.11 (3Y)
unnamed: M1.4, U3.14 (4Y)
unnamed: M2.1, U4.3 (1Y)
unnamed: M2.2 (-), U4.6 (2Y)
unnamed: M2.3, U4.11 (3Y)
unnamed: M2.4, U4.14 (4Y)
unnamed: R3.2, U1.6
unnamed: RV1.2, U1.3 (+)
unnamed: U2.11 (GND), U2.31 (GND)
unnamed: U2.18 (PD4), U4.15 (4A)
unnamed: U2.19 (PD5), U4.10 (3A)
unnamed: U2.20 (PD6), U4.2 (1A)
unnamed: U2.21 (PD7), U4.7 (2A)
unnamed: U2.26 (PC4), U3.15 (4A)
unnamed: U2.27 (PC5), U3.10 (3A)
unnamed: U2.28 (PC6), U3.2 (1A)
unnamed: U2.29 (PC7), U3.7 (2A)

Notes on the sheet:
TRAY HOLDER
TRAY PUSHER
IR SENSOR

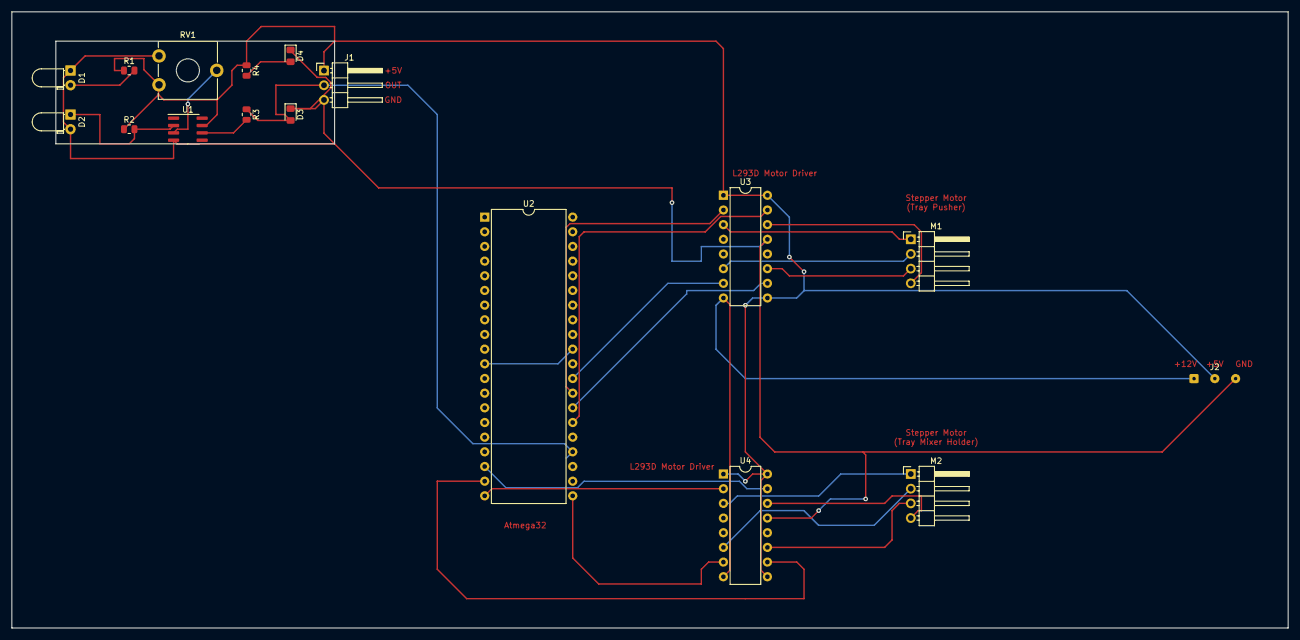
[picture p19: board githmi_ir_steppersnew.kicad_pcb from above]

Board: 2 copper layers, 221.0 x 106.7 mm, 17 parts (0 on the bottom side), 26 nets.

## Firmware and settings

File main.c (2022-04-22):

/*
 * GccApplication2.c
 *
 * Created: 12/5/2021 10:03:23 PM
 * Author : Ishanka
 */ 
#include <avr/io.h>
#include <avr/interrupt.h>
#include <string.h>
#include <util/delay.h>

#define F_CPU 8000000UL
#define BAUD 9600
#define MYUBBR F_CPU/16/BAUD-1

void pump_w();
void pump_l();
void pump_a();
void timer_1();


float calibrationFactor = 4.5;
float flowRate=0;
volatile unsigned int pulseCount=0;
unsigned long oldTime=0;
unsigned int flowMilliLitres=0;
unsigned long totalMilliLitres=0;
volatile unsigned long int millisec=0;
volatile unsigned long int sec=0;
int v_water=500;

void timer_1(){

	TCCR1A = (0 << WGM11)| (0 << WGM10 );
	TCCR1B = (0 << WGM12)| (0 << WGM13 );// normal mode
	TCCR1B |= (1 << CS12) | (1 << CS10);// set pre scaler to 1024 and start the timer
	TCNT1=0;
}


int main(void){
	DDRB = DDRB & (~(1<<2));    /*Make PB2 as input pin*/
	DDRD = DDRD & (~(1<<2));
	DDRD = DDRD & (~(1<<3));
	
	DDRB = DDRB | (1<<5);		/* Make PB5 as output pin */
	DDRB = DDRB | (1<<6);
	DDRB = DDRB | (1<<7);
	pump_w();
		_delay_ms(5000);
	/*pump_l();
		_delay_ms(5000);
	pump_a();
		_delay_ms(5000);*/
}

void pump_w(){
	PORTB = PORTB | (0<<4);
	PORTB = PORTB | (0<<3);    /*multiplexer input*/
	PORTB = PORTB | (1<<5);    /* Turn on the Relay and motor ON*/
	timer_1();
	DDRD &= ~(1 << DDD2);     /*Clear the PD2 pin*/
	PORTD = 0xFF;             /* turn On the Pull-up */
	DDRD &= ~(1<<PD2);        /* Make INT0 pin as Input */
	GICR = (1<<INT0);         /* Enable INT0*/
	MCUCR = ((1<<ISC00)|(1<<ISC01));/* Trigger INT0 on Rising Edge triggered */
	
	sei();                   /*enable interrupts*/
	while (totalMilliLitres!=v_water)   {
		if((millisec-oldTime)>=1000)
		{
			sec++;
			if(sec==1)
			{
				cli();
				
				flowRate = ((1000.0 / (millisec - oldTime)) * pulseCount) / calibrationFactor;
				oldTime = millisec;
				flowMilliLitres = (flowRate / 60) * 1000;
				totalMilliLitres += flowMilliLitres;
				}
		}
	}
	PORTB = PORTB & (~(1<<5)); /*Turn off the relay*/
	millisec=0;
	sec=0;
	pulseCount = 0;
	
	sei();
}
ISR (TIMER1_COMPA_vect){
	millisec++;
}
ISR (INT0_vect){
	pulseCount++;
}

void pump_l(){
	PORTB = PORTB | (1<<6); /* Turn on the Relay and motor ON*/
	timer_1();
	DDRD &= ~(1 << DDD2);     // Clear the PD2 pin
	PORTD = 0xFF;   // turn On the Pull-up
	DDRD &= ~(1<<PD3);		/* Make INT1 pin as Input */
	GICR = (1<<INT1);		/* Enable INT0*/
	MCUCR = ((1<<ISC10)|(1<<ISC11));/* Trigger INT1 on Rising Edge triggered */

	sei();// enable interrupts
	
	while (totalMilliLitres!=v_water*2)   {
		if((millisec-oldTime)>=1000)
		{
			sec++;
			if(sec==1)
			{
				cli();
				
				flowRate = ((1000.0 / (millisec - oldTime)) * pulseCount) / calibrationFactor;
				oldTime = millisec;
				flowMilliLitres = (flowRate / 60) * 1000;
				totalMilliLitres += flowMilliLitres;

				
			}
		}
	}
	PORTB = PORTB & (~(1<<6)); /*Turn off the relay*/
	millisec=0;
	sec=0;
	pulseCount = 0;
	
	sei();
}


ISR (INT1_vect){
	pulseCount++;
}

void pump_a(){
	PORTB = PORTB | (1<<7); /* Turn OFF the Relay and motor ON*/
	timer_1();
	DDRB &= ~(1 << DDB2);     // Clear the PD2 pin
	PORTB = 0xFF;   // turn On the Pull-up
	DDRB &= ~(1<<PB2);		/* Make INT2 pin as Input */
	GICR = (1<<INT2);		/* Enable INT0*/
	MCUCR = (1<<ISC2);/* Trigger INT2 on Rising Edge triggered */


	sei();// enable interrupts
	
	while (totalMilliLitres!=v_water/10)   {
		if((millisec-oldTime)>=1000)
		{
			sec++;
			if(sec==1)
			{
				cli();
				
				flowRate = ((1000.0 / (millisec - oldTime)) * pulseCount) / calibrationFactor;
				oldTime = millisec;
				flowMilliLitres = (flowRate / 60) * 1000;
				totalMilliLitres += flowMilliLitres;

				
			}
		}
	}
	PORTB = PORTB & (~(1<<7)); /*Turn off the relay*/
	millisec=0;
	sec=0;
	pulseCount = 0;
	
	sei();
}


ISR (INT2_vect){
	pulseCount++;
}

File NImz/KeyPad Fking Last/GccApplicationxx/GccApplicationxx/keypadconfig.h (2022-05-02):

#ifndef KEYPADCONFIG_H_
#define KEYPADCONFIG_H_

#include <avr/io.h>
//keypad pins
#define ROW0		0
#define ROW1		1
#define ROW2		2
#define ROW3		3
#define LINE0		4
#define LINE1		5
#define LINE2		6
#define LINE3		7
//KEYPAD Direction
#define ROW0_DDR		DDRD
#define ROW1_DDR		DDRD
#define ROW2_DDR		DDRD
#define ROW3_DDR		DDRD
#define LINE0_DDR		DDRD
#define LINE1_DDR		DDRD
#define LINE2_DDR		DDRD
#define LINE3_DDR		DDRD
//ROWs' PORTs
#define ROW0_PORT		PORTD
#define ROW1_PORT		PORTD
#define ROW2_PORT		PORTD
#define ROW3_PORT		PORTD
//LINEs' PINs
#define LINE0_PIN		PIND	
#define LINE1_PIN		PIND
#define LINE2_PIN		PIND
#define LINE3_PIN		PIND
//LINES' PULLUP
#define LINE0_PULLUP	PORTD
#define LINE1_PULLUP	PORTD
#define LINE2_PULLUP	PORTD
#define LINE3_PULLUP	PORTD

#endif //KEYPADCONFIG_H_

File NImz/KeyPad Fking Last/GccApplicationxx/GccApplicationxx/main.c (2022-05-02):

/*
 * test5.c
 *
 * Created: 9/16/2016 5:08:21 PM
 * Author : Ramy Elfouly
 */ 
#define F_CPU 1000000UL
#include <avr/io.h>
#include "keypad.h"
#include "lcd.h"
#include <util/delay.h>

int main(void)
{
	uint8_t data_from_keypad;
    keypad_init();
	lcd_init();
	lcd_write_string("Hello!");
	_delay_ms(1000);
	lcd_clearDisplay();
    while (1) 
    {
	data_from_keypad = keypad_scan();
	if(data_from_keypad != 0)
	{
	lcd_write_character(data_from_keypad);
	}
	
    }
}

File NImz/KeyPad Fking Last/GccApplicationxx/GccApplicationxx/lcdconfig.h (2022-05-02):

#ifndef	LCDCONFIG_H_
#define LCDCONFIG_H_

/***************************************************************************

The four data lines as well as the two control lines may be
implemented on any available I/O pin of any port.  These are
the connections used for this program:

-----------                   ----------
| ATmega32  |                 |   LCD    |
|           |                 |          |
|        PA7|---------------->|D7        |
|        PA6|---------------->|D6        |
|        PA5|---------------->|D5        |
|        PA4|---------------->|D4        |
|           |                 |D3        |
|           |                 |D2        |
|           |                 |D1        |
|           |                 |D0        |
|           |                 |          |
|        PB3|---------------->|E         |
|        PB2|---------------->|RW        |
|        PB1|---------------->|RS        |
-----------                   ----------

**************************************************************************/

#define LCD_PORT_D7     	PORTB
#define LCD_DDR_D7      	DDRB
#define D7_BIT				7

#define LCD_PORT_D6     	PORTB
#define LCD_DDR_D6      	DDRB
#define D6_BIT				6

#define LCD_PORT_D5     	PORTB
#define LCD_DDR_D5      	DDRB
#define D5_BIT				5

#define LCD_PORT_D4     	PORTB
#define LCD_DDR_D4      	DDRB
#define D4_BIT				4

//lcd Enable pin
#define E_PORT				PORTB
#define E_BIT				1
#define E_DDR				DDRB
//lcd Register Select pin
#define RS_PORT				PORTB
#define RS_BIT				0
#define RS_DDR				DDRB
//lcd Register Select pin
#define RW_PORT				PORTB
#define RW_BIT				2
#define RW_DDR				DDRB
 
#endif // LCDCONFIG_H_

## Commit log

2022-05-08 added ph 1 pin
2022-05-15 Updated main.c edited code in stpr motor fixed lcd
    [Stepper_motors.h, adc.c]
2022-06-06 final pcb
    [1.dsn, 1.kicad_pcb, 1.kicad_sch]
2022-06-06 githmi pcb
    [githmi_ir_steppersnew.kicad_pcb, githmi_ir_steppersnew.kicad_sch]
2022-06-06 ish pcb
    [204157V n.dsn, pumps.kicad_pcb, pumps.kicad_sch]
2022-06-06 milan pcb
    [5-1437657-7.step, Milan.dsn, Milan.kicad_pcb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]
2022-06-06 nish pcb
    [myproject1.kicad_pcb, myproject1.kicad_sch]
2022-06-06 final pcb last
    [final pcb.kicad_pcb, final pcb.kicad_sch]
2022-06-06 power supply
    [L7812.step, power supply.kicad_pcb, power supply.kicad_sch]
